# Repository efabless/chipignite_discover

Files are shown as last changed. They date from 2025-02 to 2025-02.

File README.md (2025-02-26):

# ChipIgnite educational FPGA dev board

This FPGA experimentation and development board was developped for [efabless chipignite](https://efabless.com/chipignite) workshops and labs to serve as an easy to use experimentation board and stepping stone towards ASIC digital design, allowing for simple migration of design to [Tiny Tapeout](https://tinytapeout.com) projects.

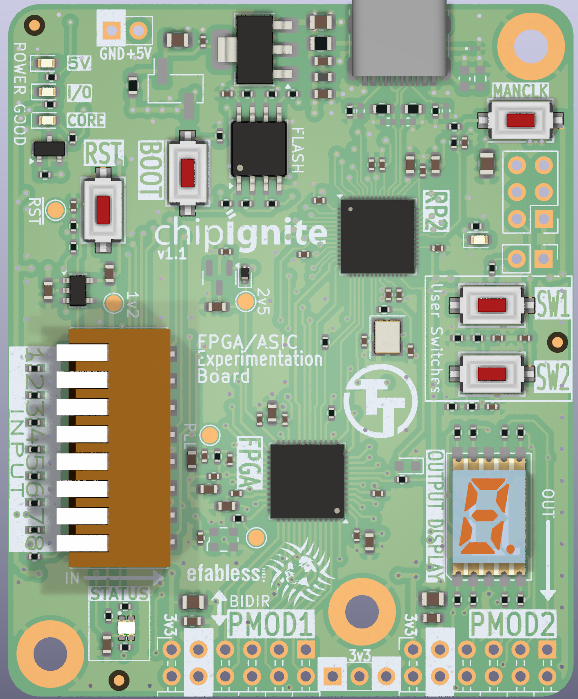
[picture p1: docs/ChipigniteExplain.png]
ChipIgnite Explain PCB


It is released as [open hardware](LICENSE), and all the design files are included here, as a[kicad](https://www.kicad.org/) project.

## Schematic

The [full schematic pdf](docs/ChipigniteExplain-schematic.pdf) is available, but is in essence:

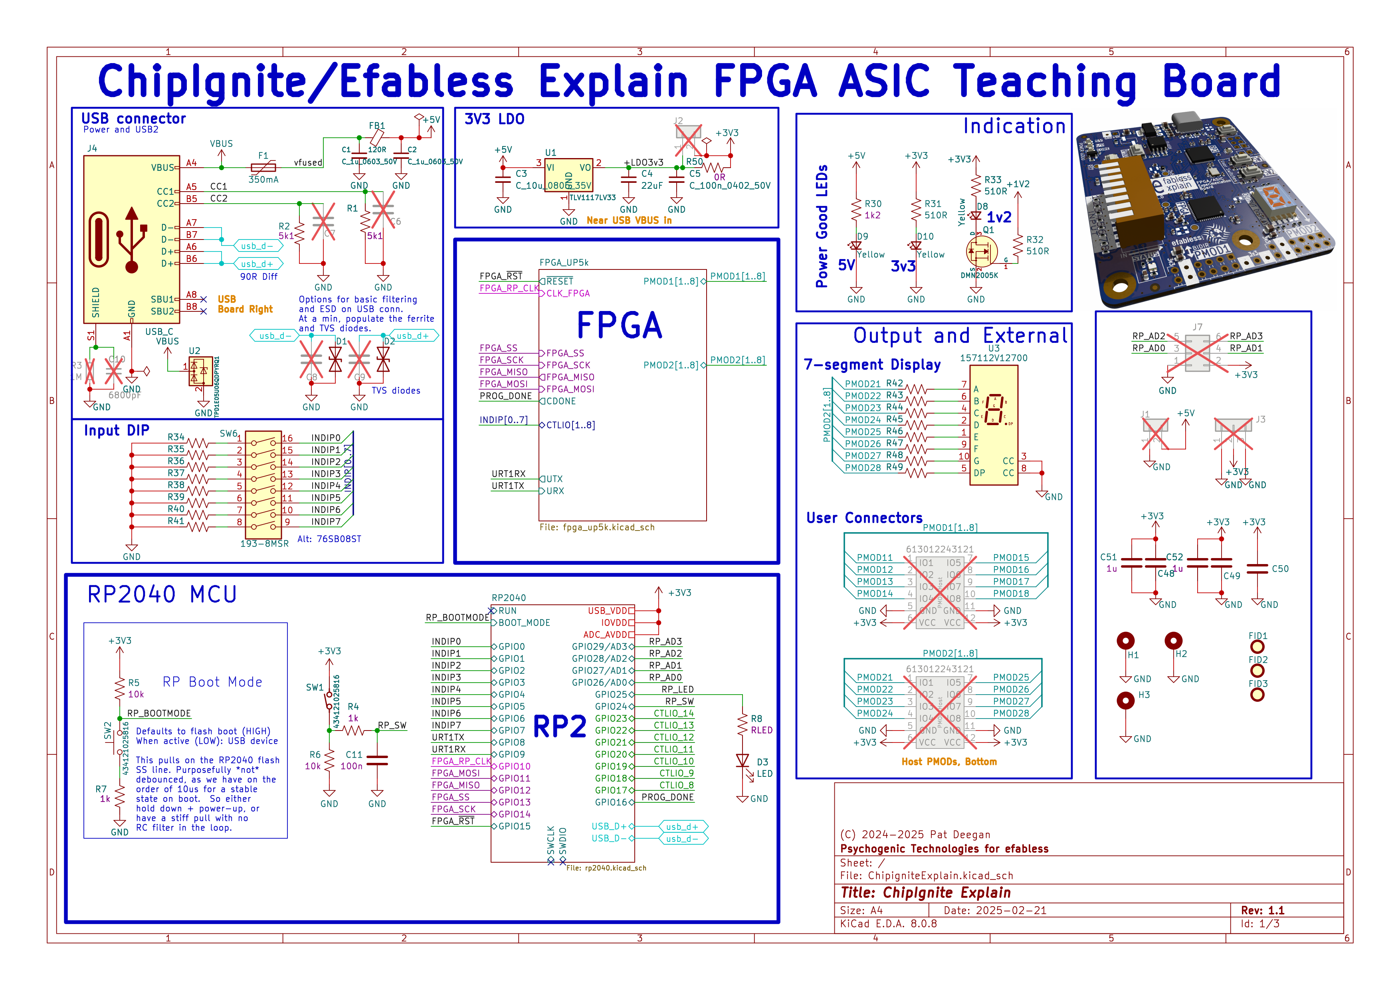
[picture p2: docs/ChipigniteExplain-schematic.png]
Schematic main page


    *  An UP5K FPGA, tied to 8 input switches, 8 outputs through a 7-segment display and 8 additional I/O (the latter two sets also appearing on Pmod headers)
    
    *  An RP2040 MCU, used to manage bitstreams and allow for easy programming of FPGA through drag & drop of UF2 files on a virtual USB drive (powered by [riffpga](https://github.com/psychogenic/riffpga) )

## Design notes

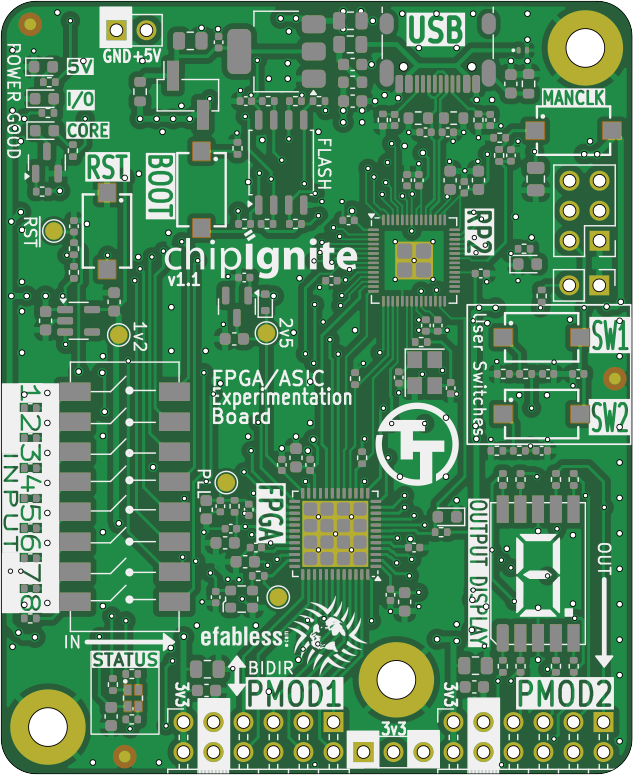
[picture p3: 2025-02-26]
ChipigniteExplain-top.png

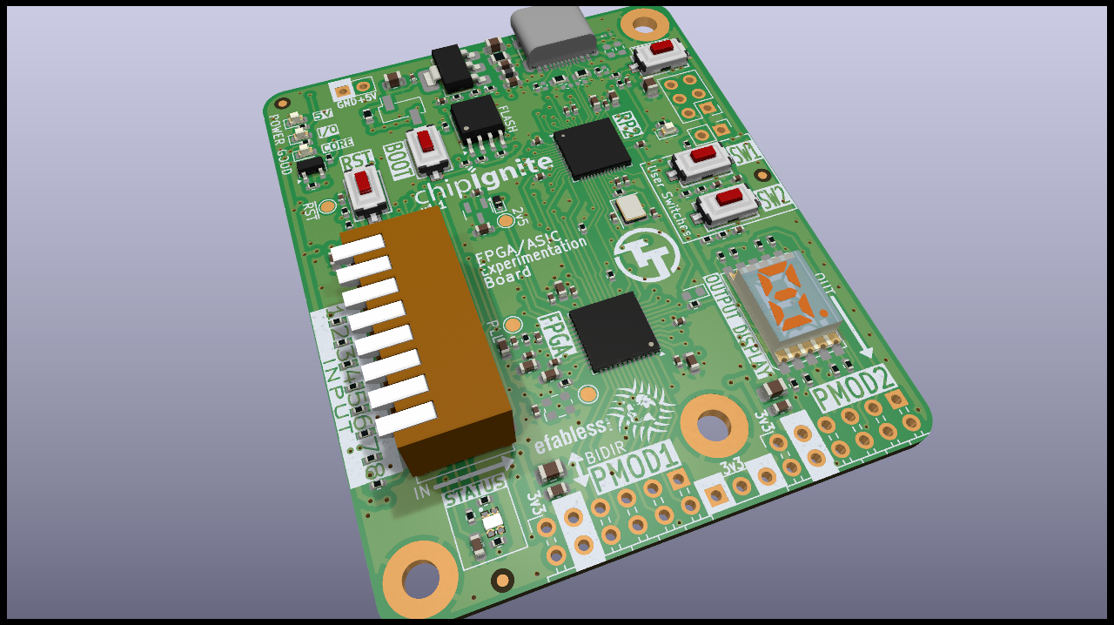
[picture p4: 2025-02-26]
ChipigniteExplain-3D_top30deg.png

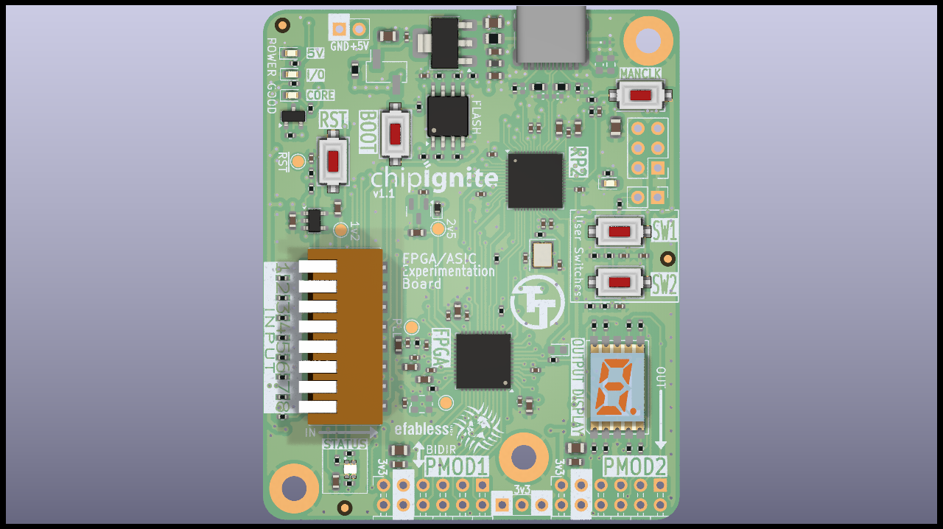
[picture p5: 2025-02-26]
ChipigniteExplain-3D_top.png

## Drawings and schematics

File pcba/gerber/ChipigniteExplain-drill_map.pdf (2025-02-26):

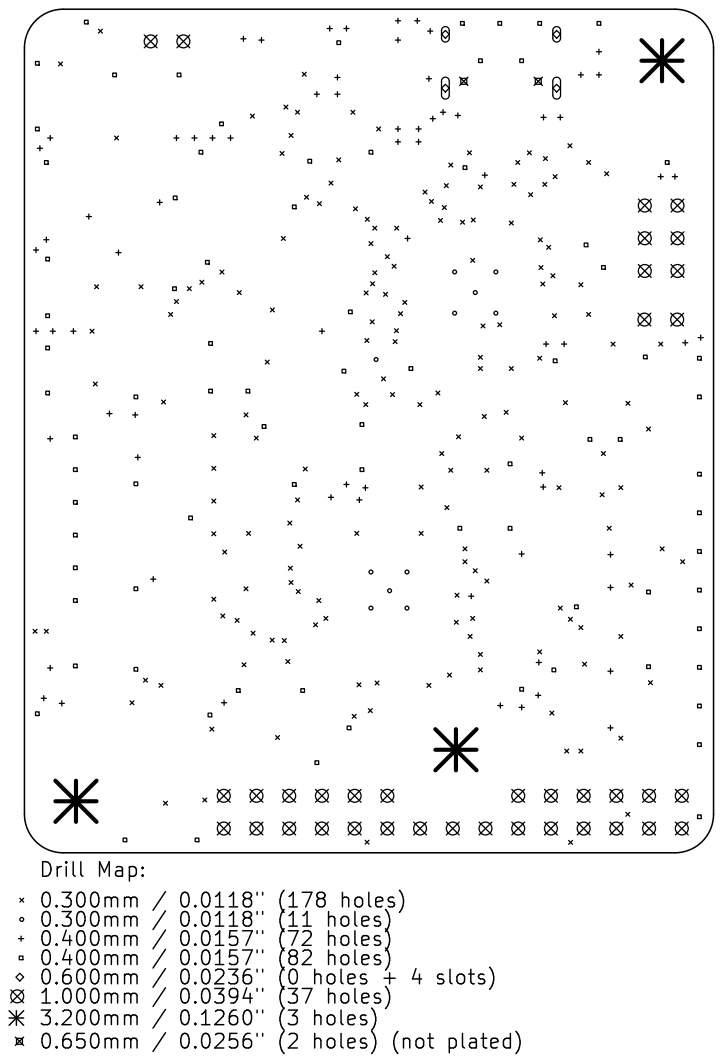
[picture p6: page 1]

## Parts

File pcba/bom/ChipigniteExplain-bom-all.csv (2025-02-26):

Row | Quantity Per PCB | Populate | References | Value | Characteristics | Footprint | Footprint Type | MPN | MPN ALT | LCSC # | Digikey # | Datasheet
1 | 2 | yes | C14 C15 | 4pF | 4pF 10% 50V XR 0402 | C_0402_1005Metric | SMD | CC0402CRNPO9BN4R0 | GRT1555C1H4R0CA02D | C325455 | 311-3643-1-ND | ~
2 | 1 | no | C10 | 6800pF |  | C_0603_1608Metric | SMD |  |  |  |  | ~
3 | 1 | yes | C4 | 22uF | 22u 6V XR 0805 | C_0805_2012Metric | SMD | CL21A226KOQNNNG | GRM21BR61A226ME51K | C86816 |  | ~
4 | 25 | yes | C5 C11 C16 C17 C18 C19 C20 C21 C22 C23 C24 C25 C27 C29 C31 C36 C37 C38 C40 C41 C42 C43 C44 C45 C47 | C_100n_0402_50V | 100n 10% 25V XR 0402 C 0402 100n | C_0402_1005Metric | SMD | GRM155R71H104KE14J | GRM155R71E104KE14J | C100072 | 490-13342-1-ND | ~
5 | 1 | yes | C39 | C_10u_0603_10V | 10u 0603 | C_0603_1608Metric | SMD | GRM188R61A106KE69D |  |  | 490-10474-1-ND | ~
6 | 4 | yes | C3 C48 C49 C50 | C_10u_0805_35V | 10u 10V XR 0805 | C_0805_2012Metric | SMD | GRM21BR6YA106KE43L | LMK212AB7106MG-T | C408142 | 490-10514-1-ND | ~
7 | 8 | yes | C1 C2 C12 C13 C33 C34 C51 C52 | C_1u_0603_50V | 1u 10V XR 0603 C 0603 1u | C_0603_1608Metric | SMD | CL10A105KA8NNNC | C0603C105K4RAC7411 | C5673 | 490-12330-1-ND | ~
8 | 4 | no | C6 C7 C8 C9 | C_33p_0402_50V | 33pF 0402 | C_0402_1005Metric | SMD | CC0402JRNPO9BN330 |  | C107005 | 311-1020-1-ND | ~
9 | 6 | yes | C26 C28 C30 C32 C35 C46 | C_4p7u_0603_25V | C 0603 4u7 4.7u 10% 0603 | C_0603_1608Metric | SMD | GRM188R61E475KE11D |  |  | 490-7203-1-ND | ~
10 | 1 | yes | D4 | 1N4448WT | DIODE GEN PURP 75V 200MA SOD523F | D_SOD-523 | SMD | 1N4448WT |  | C967981 or C5277952 | 1N4448WTCT-ND | http://www.mouser.com/ds/2/149/1N4148WT-461550.pdf
11 | 1 | no | D5 | BAS19 | DIODE GP 120V 200MA SOT23-3 Vf 1.2V | SOT-23 | SMD | BAS19LT1G | MMBD4148 / C513459 | C232582 | BAS19LT1GOSCT-ND | https://www.diodes.com/assets/Datasheets/Ds12004.pdf
12 | 1 | yes | D3 | LED | Red LED 0603 | LED_0603_1608Metric | SMD |  |  |  |  | ~
13 | 1 | no | D6 | LED | Yellow LED 0603 | LED_0603_1608Metric | SMD |  |  |  |  | ~
14 | 1 | yes | D7 | RGB | RGB LED | LED_EAST1616RGBA3 | SMD | EAST1616RGBB4 |  |  | 1080-1552-1-ND | https://everlightamericas.com/index.php?controller=attachment&id_attachment=2827
15 | 2 | yes | D1 D2 | TVS | Bidir TVS Diode | R_0603_1608Metric | SMD | 0603ESDA-AEC1 | C6961594 | C6961594 | 283-0603ESDA-AEC1CT-ND | https://www.eaton.com/content/dam/eaton/products/electronic-components/resources/data-sheet/eaton-0603esda-aec1-automotive-esd-suppressor-data-sheet-elx1146-e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
16 | 3 | yes | D8 D9 D10 | Yellow | Yellow LED, Low 1.8 V Vf | LED_0603_1608Metric | SMD | CSL1901YW1 | LY L29K-H1K2-26-Z | C72038 |  | ~
17 | 1 | yes | F1 | 350mA | PTC Reset Fuse, 350mA Hold, 0805 | Fuse_0805_2012Metric | SMD | 0ZCK0035FF2G | SMD0805B035TF | C1884490 |  | ~
18 | 1 | yes | FB1 | 120R | FERRITE BEAD 120R 0603 | L_0603_1608Metric | SMD | MFBM1V1608-121-R | HFZ 1608PF-151T25 | C2649119 | 283-MFBM1V1608-121-RCT-ND | ~
19 | 2 | no | J5 J6 | 613012243121 |  | PinSocket_2x06_P2.54mm_PMODHost1A | THT
20 | 2 | no | J1 J10 | Conn_01x02 |  | PinHeader_1x02_P2.54mm_Vertical | THT |  |  |  |  | https://cdn.amphenol-cs.com/media/wysiwyg/files/drawing/10129380.pdf
21 | 1 | no | J2 | Conn_01x02 |  | PinHeader_1x02_P2.54mm_Vertical_SMD_Pin1Right | SMD | 10129380-902001BLF | GEC02SABN-M30 |  |  | https://cdn.amphenol-cs.com/media/wysiwyg/files/drawing/10129380.pdf
22 | 1 | no | J3 | Conn_01x03 |  | PinHeader_1x03_P2.54mm_Vertical | THT |  |  |  |  | ~
23 | 1 | no | J11 | Conn_01x06 |  | PinHeader_1x06_P2.54mm_Vertical_SMD_Pin1Right | SMD | 61300611121 |  |  |  | https://www.we-online.com/components/products/datasheet/61300611121.pdf
24 | 1 | no | J7 | Conn_02x03_Odd_Even |  | PinHeader_2x03_P2.54mm_Vertical | THT |  |  |  |  | ~
25 | 1 | yes | J4 | USB_C | USB C Right Angle 16P Female USB 2.0 PD | USB_C_Receptacle_HRO_TYPE-C-31-M-12 | SMD | USB-TYPE-C-019 | TYPE-611A-T3 | C2927039 | USB4105-GF-A-120 | https://datasheet.lcsc.com/lcsc/2402010910_DEALON-USB-TYPE-C-019_C2927039.pdf
26 | 1 | yes | Q1 | DMN2005K | N-ch MOSFET Vth < 1.5 | SOT-23 | SMD | DMN2005K-7 | SI2302DDS-T1-BE3 | C2891732 | DMN2005K-7DICT-ND | https://www.diodes.com/assets/Datasheets/ds30734.pdf
27 | 19 | yes | R31 R32 R33 R34 R35 R36 R37 R38 R39 R40 R41 R42 R43 R44 R45 R46 R47 R48 R49 | 510R |  | R_0402_1005Metric | SMD |  |  |  |  | ~
28 | 1 | no | R3 | 1M | 1M 0603 | R_0603_1608Metric | SMD |  |  | C858907 |  | ~
29 | 1 | yes | R8 | RLED |  | R_0402_1005Metric | SMD |  |  |  |  | ~
30 | 1 | yes | R50 | R_0R_0603_JUMPER |  | R_0603_1608Metric | SMD | CRG0603ZR |  |  | A106051CT-ND | ~
31 | 3 | yes | R17 R24 R25 | R_100R_0402 | R 0402 100R | R_0402_1005Metric | SMD | RC0402FR-07100RL |  |  | 311-100LRCT-ND | ~
32 | 14 | yes | R5 R6 R9 R11 R12 R13 R14 R15 R16 R18 R19 R22 R23 R28 | R_10k_0402 | R 0402 10k 10k 0402 | R_0402_1005Metric | SMD | RC0402FR-0710KL | WR04X1002FTL | C471764 | 10-ERJ-U02F1002XCT-ND | ~
33 | 1 | yes | R30 | R_1k2_0402 |  | R_0402_1005Metric | SMD | RC0402FR-071K2L |  |  | 311-1.20KLRCT-ND | ~
34 | 6 | yes | R4 R7 R10 R20 R21 R29 | R_1k_0402 | R 0402 1k5 1% 1k 0402 | R_0402_1005Metric | SMD | CR0402-FX-1001GLF | WR04X1001FTL | C202394 | CR0402-FX-1001GLFCT-ND | ~
35 | 2 | yes | R1 R2 | R_5k1_0402 |  | R_0402_1005Metric | SMD | CR0402-FX-5101GLF | RC0402FR-135K1L |  | CR0402-FX-5101GLFCT-ND | ~
36 | 2 | yes | R26 R27 | R_68R_0402 |  | R_0402_1005Metric | SMD | CR0402-FX-68R0GLF | WR04X68R0FTL |  | CR0402-FX-68R0GLFCT-ND | ~
37 | 1 | yes | SW6 | 193-8MSR | 8 POS SPST DIP PIANO | GENERIC_PIANO_8DIP | SMD | DSPV08LSGET | 2.54-8P TPCB | C3293170 | CT3100CT-ND | https://www.ctscorp.com/files/datasheets/switches/dip-switches/cts-switches-dip-193-series-datasheet.pdf
38 | 5 | yes | SW1 SW2 SW3 SW4 SW5 | 434121025816 | SWITCH TACTILE SPST-NO MOM SPST NO | 434121025816 | SMD | 434121025816 | TS09-63-25-R-260-SMT-TR | C4364640 or C2689642 or C329185 or C2689642 | 2223-TS09-63-25-R-260-SMT-TRCT-ND | https://www.cuidevices.com/product/resource/ts09.pdf
39 | 1 | yes | U3 | 157112V12700 | 7 SEGMENT COMMON CATHODE | WL_S7DS-157112V12700 | SMD | 157112V12700 | GS3011CR-G | C6976938 | 732-157112V12700DKR-ND | https://www.we-online.com/catalog/datasheet/157112V12700.pdf
40 | 1 | yes | U6 | AP2112K-1.2 | IC REG LINEAR 1.2V 600MA SOT25 | SOT-23-5 | SMD | AP2112K-1.2TRG1 |  | C460310 | 31-AP2112K-1.2TRG1CT-ND | https://www.diodes.com/assets/Datasheets/AP2112.pdf
41 | 1 | yes | U7 | ICE40UP5K-SG48ITR |  | QFN-48-1EP_7x7mm_P0.5mm_EP5.6x5.6mm | SMD | ICE40UP5K-SG48ITR |  |  |  | http://www.latticesemi.com/Products/FPGAandCPLD/iCE40Ultra
42 | 1 | yes | U4 | RP2040 |  | QFN-56-1EP_7x7mm_P0.4mm_EP3.2x3.2mm | SMD | SC0914(13) |  | C2040 | 2648-SC0914(13)CT-ND | https://datasheets.raspberrypi.com/rp2040/rp2040-datasheet.pdf
43 | 1 | yes | U1 | TLV1117LV33 | VREG 3.3V SOT-223-4 | SOT-223-3_TabPin2 | SMD | TLV1117LV33DCYR | AZ1117CH-3.3TRG1 | C15578 |  | https://www.ti.com/lit/ds/symlink/tlv1117lv.pdf
44 | 1 | yes | U2 | TPD1E05U06QDPYRQ1 | TVS DIODE 5.5VWM 14VC 2X1SON | Texas_DPY0002A_0.6x1mm_P0.65mm | SMD | TPD1E05U06QDPYRQ1 | TPD1E05U06DPYR |  | 296-47863-1-ND | https://www.ti.com/lit/ds/symlink/tpd1e05u06-q1.pdf
45 | 1 | yes | U5 | W25Q32JVSS | RP2040 FLASH | SOIC-8_5.23x5.23mm_P1.27mm | SMD | W25Q32JVSSIQ |  | C82344 | W25Q32JVSSIQ-ND | http://www.winbond.com/resource-files/w25q32jv%20revg%2003272018%20plus.pdf
46 | 1 | no | X1 | 24MHz | XTAL OSC XO 24.0000MHZ CMOS SMD | Oscillator_SMD_ECS_2520MV-xxx-xx-4Pin_2.5x2.0mm | SMD | KC2520Z24.0000C1KX00 | SIT8008AC-11-XXE-24.000000 |  | 478-KC2520Z24.0000C1KX00DKR-ND | https://www.ecsxtal.com/store/pdf/ECS-2520MV.pdf
47 | 1 | yes | Y1 | 12.0MHz | 12.000MHz 10ppm stability | Crystal_SMD_3225-4Pin_3.2x2.5mm | SMD | ABM8W-12.0000MHZ-7-B1U-T3 | ABM8W-12.0000MHZ-8-D1X-T3 | C1985523 | 535-14005-1-ND | https://abracon.com/datasheets/ABM8W.pdf
Project info:
Schematic: | ChipigniteExplain
Variant: | default
Revision: | 1.1
Date: | 2025-02-21
KiCad Version: | 8.0.8-8.0.8-0~ubuntu24.04.1
Statistics:
Component Groups: | 47
Component Count: | 139 (132 SMD/ 6 THT)
Fitted Components: | 122 (121 SMD/ 0 THT)
Number of PCBs: | 1
Total Components: | 122

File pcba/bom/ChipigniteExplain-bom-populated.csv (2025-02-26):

Row | Quantity Per PCB | References | Value | Characteristics | Footprint | Footprint Type | MPN | MPN ALT | LCSC # | Digikey # | Datasheet
1 | 2 | C14 C15 | 4pF | 4pF 10% 50V XR 0402 | C_0402_1005Metric | SMD | CC0402CRNPO9BN4R0 | GRT1555C1H4R0CA02D | C325455 | 311-3643-1-ND | ~
2 | 1 | C4 | 22uF | 22u 6V XR 0805 | C_0805_2012Metric | SMD | CL21A226KOQNNNG | GRM21BR61A226ME51K | C86816 |  | ~
3 | 25 | C5 C11 C16 C17 C18 C19 C20 C21 C22 C23 C24 C25 C27 C29 C31 C36 C37 C38 C40 C41 C42 C43 C44 C45 C47 | C_100n_0402_50V | 100n 10% 25V XR 0402 C 0402 100n | C_0402_1005Metric | SMD | GRM155R71H104KE14J | GRM155R71E104KE14J | C100072 | 490-13342-1-ND | ~
4 | 1 | C39 | C_10u_0603_10V | 10u 0603 | C_0603_1608Metric | SMD | GRM188R61A106KE69D |  |  | 490-10474-1-ND | ~
5 | 4 | C3 C48 C49 C50 | C_10u_0805_35V | 10u 10V XR 0805 | C_0805_2012Metric | SMD | GRM21BR6YA106KE43L | LMK212AB7106MG-T | C408142 | 490-10514-1-ND | ~
6 | 8 | C1 C2 C12 C13 C33 C34 C51 C52 | C_1u_0603_50V | 1u 10V XR 0603 C 0603 1u | C_0603_1608Metric | SMD | CL10A105KA8NNNC | C0603C105K4RAC7411 | C5673 | 490-12330-1-ND | ~
7 | 6 | C26 C28 C30 C32 C35 C46 | C_4p7u_0603_25V | C 0603 4u7 4.7u 10% 0603 | C_0603_1608Metric | SMD | GRM188R61E475KE11D |  |  | 490-7203-1-ND | ~
8 | 1 | D4 | 1N4448WT | DIODE GEN PURP 75V 200MA SOD523F | D_SOD-523 | SMD | 1N4448WT |  | C967981 or C5277952 | 1N4448WTCT-ND | http://www.mouser.com/ds/2/149/1N4148WT-461550.pdf
9 | 1 | D3 | LED | Red LED 0603 | LED_0603_1608Metric | SMD |  |  |  |  | ~
10 | 1 | D7 | RGB | RGB LED | LED_EAST1616RGBA3 | SMD | EAST1616RGBB4 |  |  | 1080-1552-1-ND | https://everlightamericas.com/index.php?controller=attachment&id_attachment=2827
11 | 2 | D1 D2 | TVS | Bidir TVS Diode | R_0603_1608Metric | SMD | 0603ESDA-AEC1 | C6961594 | C6961594 | 283-0603ESDA-AEC1CT-ND | https://www.eaton.com/content/dam/eaton/products/electronic-components/resources/data-sheet/eaton-0603esda-aec1-automotive-esd-suppressor-data-sheet-elx1146-e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
12 | 3 | D8 D9 D10 | Yellow | Yellow LED, Low 1.8 V Vf | LED_0603_1608Metric | SMD | CSL1901YW1 | LY L29K-H1K2-26-Z | C72038 |  | ~
13 | 1 | F1 | 350mA | PTC Reset Fuse, 350mA Hold, 0805 | Fuse_0805_2012Metric | SMD | 0ZCK0035FF2G | SMD0805B035TF | C1884490 |  | ~
14 | 1 | FB1 | 120R | FERRITE BEAD 120R 0603 | L_0603_1608Metric | SMD | MFBM1V1608-121-R | HFZ 1608PF-151T25 | C2649119 | 283-MFBM1V1608-121-RCT-ND | ~
15 | 1 | J4 | USB_C | USB C Right Angle 16P Female USB 2.0 PD | USB_C_Receptacle_HRO_TYPE-C-31-M-12 | SMD | USB-TYPE-C-019 | TYPE-611A-T3 | C2927039 | USB4105-GF-A-120 | https://datasheet.lcsc.com/lcsc/2402010910_DEALON-USB-TYPE-C-019_C2927039.pdf
16 | 1 | Q1 | DMN2005K | N-ch MOSFET Vth < 1.5 | SOT-23 | SMD | DMN2005K-7 | SI2302DDS-T1-BE3 | C2891732 | DMN2005K-7DICT-ND | https://www.diodes.com/assets/Datasheets/ds30734.pdf
17 | 19 | R31 R32 R33 R34 R35 R36 R37 R38 R39 R40 R41 R42 R43 R44 R45 R46 R47 R48 R49 | 510R |  | R_0402_1005Metric | SMD |  |  |  |  | ~
18 | 1 | R8 | RLED |  | R_0402_1005Metric | SMD |  |  |  |  | ~
19 | 1 | R50 | R_0R_0603_JUMPER |  | R_0603_1608Metric | SMD | CRG0603ZR |  |  | A106051CT-ND | ~
20 | 3 | R17 R24 R25 | R_100R_0402 | R 0402 100R | R_0402_1005Metric | SMD | RC0402FR-07100RL |  |  | 311-100LRCT-ND | ~
21 | 14 | R5 R6 R9 R11 R12 R13 R14 R15 R16 R18 R19 R22 R23 R28 | R_10k_0402 | R 0402 10k 10k 0402 | R_0402_1005Metric | SMD | RC0402FR-0710KL | WR04X1002FTL | C471764 | 10-ERJ-U02F1002XCT-ND | ~
22 | 1 | R30 | R_1k2_0402 |  | R_0402_1005Metric | SMD | RC0402FR-071K2L |  |  | 311-1.20KLRCT-ND | ~
23 | 6 | R4 R7 R10 R20 R21 R29 | R_1k_0402 | R 0402 1k5 1% 1k 0402 | R_0402_1005Metric | SMD | CR0402-FX-1001GLF | WR04X1001FTL | C202394 | CR0402-FX-1001GLFCT-ND | ~
24 | 2 | R1 R2 | R_5k1_0402 |  | R_0402_1005Metric | SMD | CR0402-FX-5101GLF | RC0402FR-135K1L |  | CR0402-FX-5101GLFCT-ND | ~
25 | 2 | R26 R27 | R_68R_0402 |  | R_0402_1005Metric | SMD | CR0402-FX-68R0GLF | WR04X68R0FTL |  | CR0402-FX-68R0GLFCT-ND | ~
26 | 1 | SW6 | 193-8MSR | 8 POS SPST DIP PIANO | GENERIC_PIANO_8DIP | SMD | DSPV08LSGET | 2.54-8P TPCB | C3293170 | CT3100CT-ND | https://www.ctscorp.com/files/datasheets/switches/dip-switches/cts-switches-dip-193-series-datasheet.pdf
27 | 5 | SW1 SW2 SW3 SW4 SW5 | 434121025816 | SWITCH TACTILE SPST-NO MOM SPST NO | 434121025816 | SMD | 434121025816 | TS09-63-25-R-260-SMT-TR | C4364640 or C2689642 or C329185 or C2689642 | 2223-TS09-63-25-R-260-SMT-TRCT-ND | https://www.cuidevices.com/product/resource/ts09.pdf
28 | 1 | U3 | 157112V12700 | 7 SEGMENT COMMON CATHODE | WL_S7DS-157112V12700 | SMD | 157112V12700 | GS3011CR-G | C6976938 | 732-157112V12700DKR-ND | https://www.we-online.com/catalog/datasheet/157112V12700.pdf
29 | 1 | U6 | AP2112K-1.2 | IC REG LINEAR 1.2V 600MA SOT25 | SOT-23-5 | SMD | AP2112K-1.2TRG1 |  | C460310 | 31-AP2112K-1.2TRG1CT-ND | https://www.diodes.com/assets/Datasheets/AP2112.pdf
30 | 1 | U7 | ICE40UP5K-SG48ITR |  | QFN-48-1EP_7x7mm_P0.5mm_EP5.6x5.6mm | SMD | ICE40UP5K-SG48ITR |  |  |  | http://www.latticesemi.com/Products/FPGAandCPLD/iCE40Ultra
31 | 1 | U4 | RP2040 |  | QFN-56-1EP_7x7mm_P0.4mm_EP3.2x3.2mm | SMD | SC0914(13) |  | C2040 | 2648-SC0914(13)CT-ND | https://datasheets.raspberrypi.com/rp2040/rp2040-datasheet.pdf
32 | 1 | U1 | TLV1117LV33 | VREG 3.3V SOT-223-4 | SOT-223-3_TabPin2 | SMD | TLV1117LV33DCYR | AZ1117CH-3.3TRG1 | C15578 |  | https://www.ti.com/lit/ds/symlink/tlv1117lv.pdf
33 | 1 | U2 | TPD1E05U06QDPYRQ1 | TVS DIODE 5.5VWM 14VC 2X1SON | Texas_DPY0002A_0.6x1mm_P0.65mm | SMD | TPD1E05U06QDPYRQ1 | TPD1E05U06DPYR |  | 296-47863-1-ND | https://www.ti.com/lit/ds/symlink/tpd1e05u06-q1.pdf
34 | 1 | U5 | W25Q32JVSS | RP2040 FLASH | SOIC-8_5.23x5.23mm_P1.27mm | SMD | W25Q32JVSSIQ |  | C82344 | W25Q32JVSSIQ-ND | http://www.winbond.com/resource-files/w25q32jv%20revg%2003272018%20plus.pdf
35 | 1 | Y1 | 12.0MHz | 12.000MHz 10ppm stability | Crystal_SMD_3225-4Pin_3.2x2.5mm | SMD | ABM8W-12.0000MHZ-7-B1U-T3 | ABM8W-12.0000MHZ-8-D1X-T3 | C1985523 | 535-14005-1-ND | https://abracon.com/datasheets/ABM8W.pdf
Project info:
Schematic: | ChipigniteExplain
Variant: | default
Revision: | 1.1
Date: | 2025-02-21
KiCad Version: | 8.0.8-8.0.8-0~ubuntu24.04.1
Statistics:
Component Groups: | 47
Component Count: | 139 (132 SMD/ 6 THT)
Fitted Components: | 122 (121 SMD/ 0 THT)
Number of PCBs: | 1
Total Components: | 122
